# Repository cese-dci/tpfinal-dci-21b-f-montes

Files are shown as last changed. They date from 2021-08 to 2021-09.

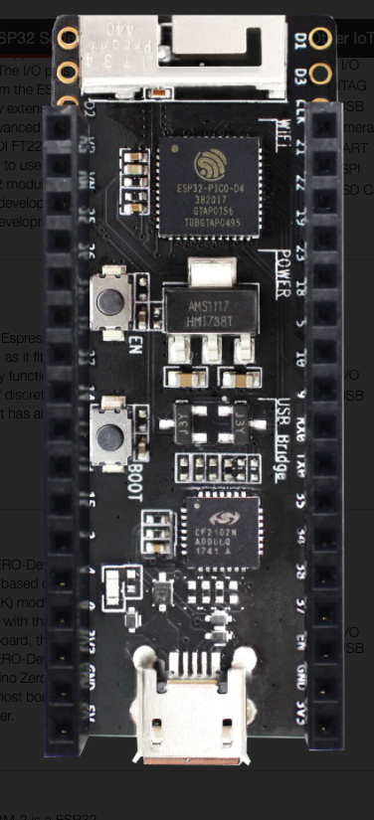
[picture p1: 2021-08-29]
info/ESP32-PICO-KIT_Vista_Superior_2.png

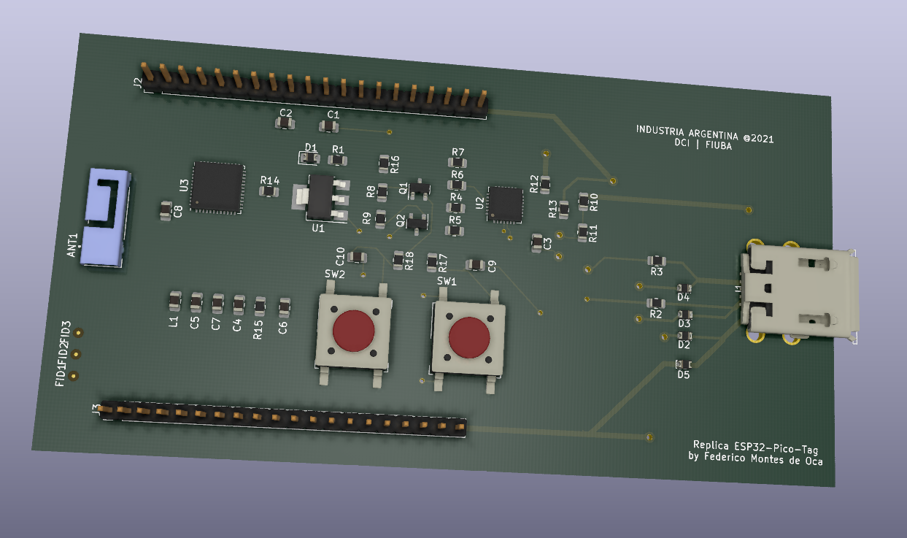
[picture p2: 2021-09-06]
pcb/MontesDeOca_DCI_CEIoT_Final_3D.png

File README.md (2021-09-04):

## Trabajo práctico final de la asignatura DCI ##
Este repositorio contiene el trabajo práctico final para la asignatura de Diseño de Circuitos Impresos de la carrera de posgrado de FIUBA.

* Autor: FEDERICO MONTES DE OCA
* Título corto del trabajo: REPLICA ESP32-PICO-KIT
* Descripción:  Circuito Impreso Replica de Modulo ESP32-PICO-KIT

## Licencia de este trabajo ##
Licencia OHL. Para detalles ver https://ohwr.org/cernohl

## Estructura del Repo ##

El repo cuenta con tres directorios principales donde encontraremos lo siguiente:

* doc: Toda la información sobre el circuito, principalmente propia:
  * Documnetacion de trabajo del autor
* info: Toda la iformación recolectada, principalmente de terceros:
  * Esquematicos provistos por el fabricante
  * BOM provista por el fabricante
  * PCB provistos por el fabricante
  * Info en internet
* pcb: Archivos de diseño esquemático y pcb propios.

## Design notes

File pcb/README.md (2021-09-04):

## Archivos Kicad ##

En este directorio se incluyen:

* Archivos de proyecto.
* Esquemático.
* PCB.
* Modelos  3D.
* Bibliotecas de símbolos y huellas externas.

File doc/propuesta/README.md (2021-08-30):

## Propuesta ##

Se adjunta aqui el material originalmente considerado para realizar el trabajo. Se incluye hipervinculo a la web del fabricante con todo el detalle: https://docs.espressif.com/projects/esp-idf/en/latest/esp32/hw-reference/esp32/get-started-pico-kit.html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

Tambien se adjuntan fotografias y esquematico tomado como referencias.

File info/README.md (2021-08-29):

## Información complementaria ##
Se adjuntan los pdf disponibilizados por el fabricante (ESPRESSIF) que poseen un importante nivel de detalle.

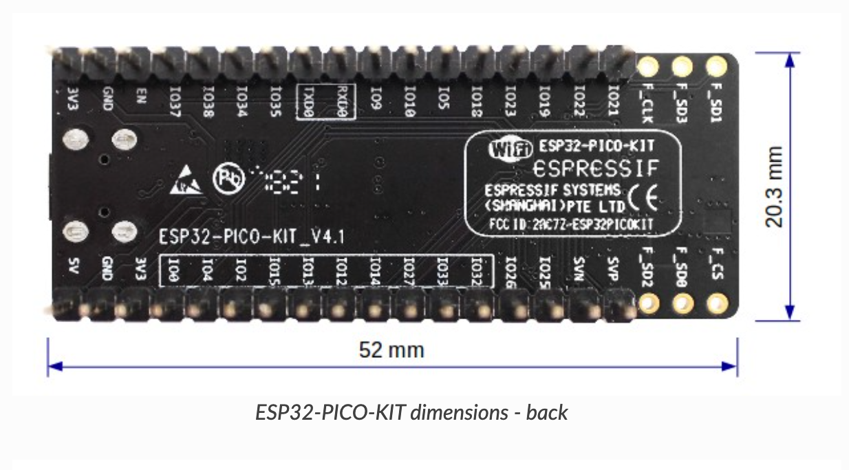
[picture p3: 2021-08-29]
info/ESP32-PICO-KIT_Vista_Inferior.png

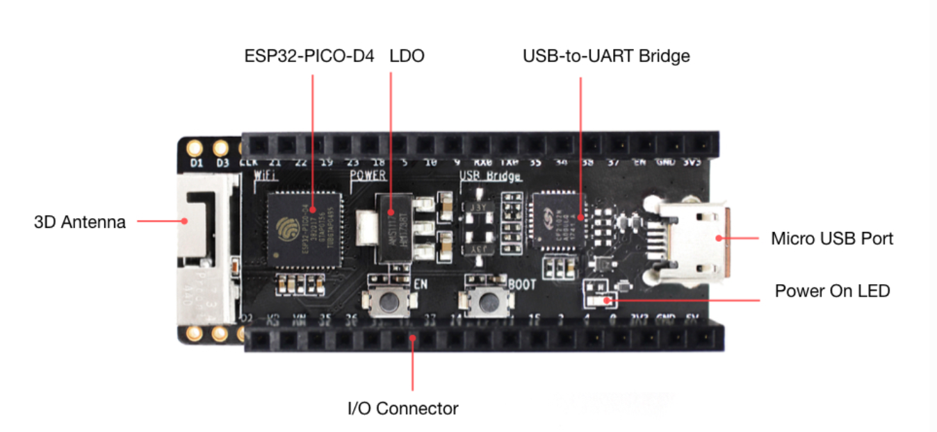
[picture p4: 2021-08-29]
info/ESP32-PICO-KIT_Vista_Superior.png

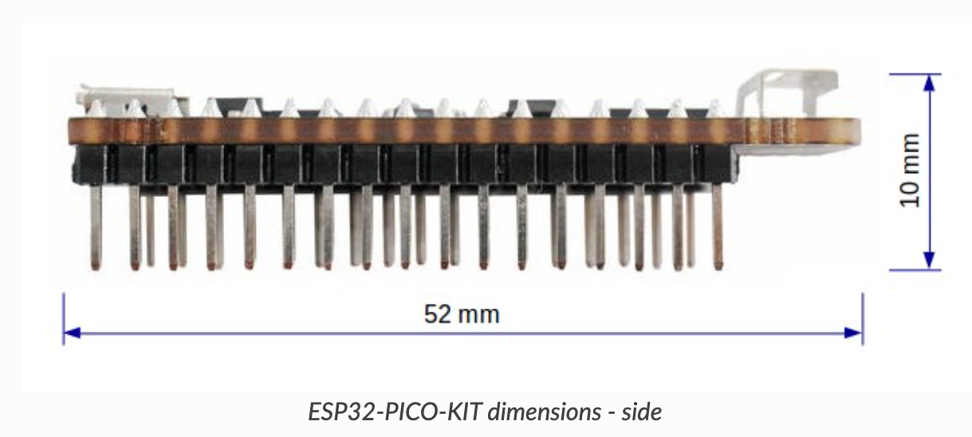
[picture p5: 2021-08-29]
info/ESP32-PICO-KIT_Vista_Lateral.png

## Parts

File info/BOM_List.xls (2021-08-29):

ESP32-PICO-KIT_V4.1 BOM_List(V0.9)
ID | Qty | Ref Des | Value | Package | ICs | Description
1 | 1 | ANT1 | Proant440 | PROANTONBOARD440 | Antenna | 3D Antenna
2 | 2 | C2,C4 | 10uF/25V(10%) | 0603C | Capacitance | Ceramic Capacitor
3 | 5 | C6,C7,C12,C16,C19 | 0.1uF/25V(10%) | 0402C | Capacitance | Ceramic Capacitor
4 | 1 | C15 | 10uF/6.3V(10%) | 0402C | Capacitance | Ceramic Capacitor
5 | 1 | C17 | 2.7pF±0.5pF/25V | 0402C | Capacitor | Ceramic Capacitor
6 | 1 | C18 | 1.6nH±0.3nH | 0402C | Inductor | Inductor
7 | 1 | D1 | RED LED | 0603D/A | LED | Red LED
8 | 1 | D2 | BAT760-7 | SOD-323 | Diode | Diode
9 | 3 | D3,D4,D5 | LESD5D5.0CT1G | SOD-523 | ESD | ESD 5V
10 | 1 | J1 | USB_CON8 | USB_5P | Connector | USB Connector
11 | 2 | J2,J3 | 2.54mm single-row pin headers 17P | CON20_2P54 | Connector | Male Header
12 | 1 | L1 | 4.7pF±0.5pF/25V | 0402C | Capacitor | Ceramic Capacitor
13 | 2 | Q1,Q2 | S8050(NPN) | SOT-23-3 | Transistor | Transistor(NPN)
14 | 2 | R1,R27 | 2K(1%) | 0402R | Resistor | Resistor
15 | 5 | R3,R4,R6,R7,R21 | 0R(1%) | 0402R | Resistor | Resistor
16 | 2 | R15,R16 | 1K(1%) | 0402R | Resistor | Resistor
17 | 3 | R19,R20,R22 | 10K(1%) | 0402R | Resistor | Resistor
18 | 1 | R24 | 22.1K(1%) | 0402R | Resistor | Resistor
19 | 1 | R26 | 47.5K(1%) | 0402R | Resistor | Resistor
20 | 2 | SW1,SW2 | SW PUSHBUTTON | SW_3X4X2MM | Push Button | Push Button
21 | 1 | U1 | AMS1117-3.3 | SOT-223 | Power IC | Power IC
22 | 1 | U4 | CP2102N | QFN28-5X5-0P5 | IC Chip | USB2UART Bridge
23 | 1 | U5 | ESP32-PICO-D4 | QFN48_7X7 | IC Chip | ESP32-SIP

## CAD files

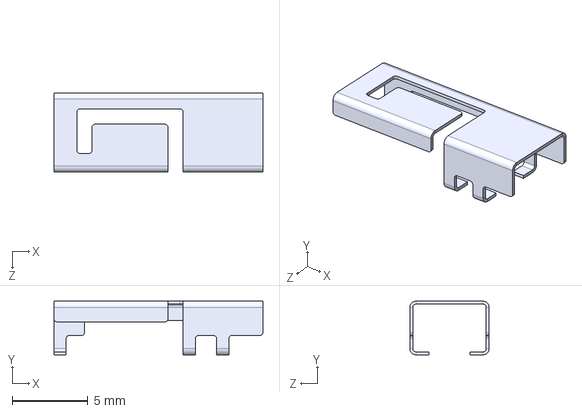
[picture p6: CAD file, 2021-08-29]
pcb/PRO-OB-440.step
13.8 x 3.53 x 5.23 mm

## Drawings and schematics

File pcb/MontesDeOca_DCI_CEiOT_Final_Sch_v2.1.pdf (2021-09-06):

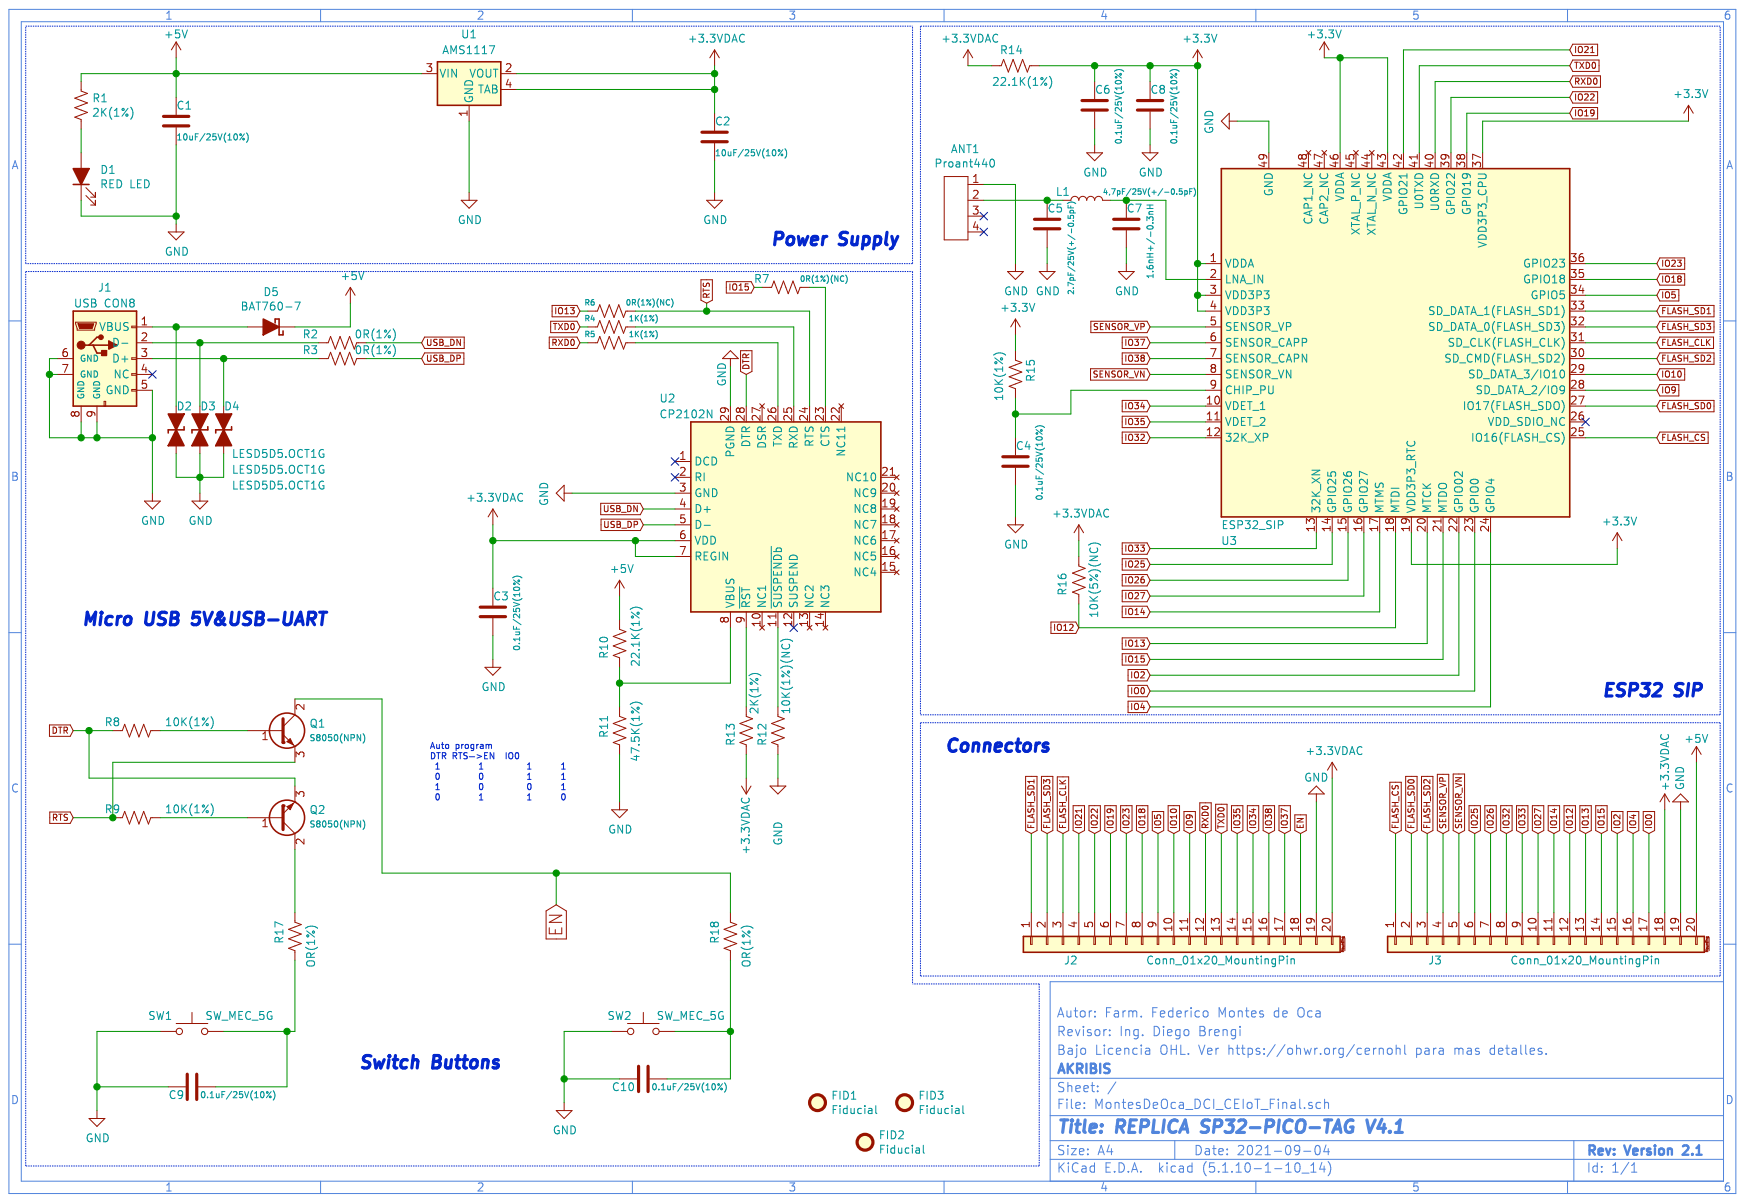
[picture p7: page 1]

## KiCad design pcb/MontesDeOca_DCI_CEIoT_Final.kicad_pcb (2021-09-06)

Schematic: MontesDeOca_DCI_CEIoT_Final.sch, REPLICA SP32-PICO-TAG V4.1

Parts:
ANT1: Proant440; ANT_PRO-OB-440
C1, C2: 10uF/25V(10%); C_0805_2012Metric
C3, C4, C6, C8, C9, C10: 0.1uF/25V(10%); C_0805_2012Metric
C5: 2.7pF/25V(+/-0.5pF); C_0805_2012Metric
C7: 1.6nH+/-0.3nH; C_0805_2012Metric
D1: RED LED; LED_0805_2012Metric
D2, D3, D4: LESD5D5.OCT1G; D_SOD-523
D5: BAT760-7; D_SOD-523
FID1, FID2, FID3: Fiducial; Fiducial_0.5mm_Mask1.5mm
J1: USB CON8; USB_A_Wuerth_61400826021_Horizontal_Stacked; Manufacturer Part # DX4R005JJ2R1800
J2, J3: Conn_01x20_MountingPin; PinHeader_1x20_P2.54mm_Vertical
L1: 4,7pF/25V(+/-0.5pF); C_0805_2012Metric
Q1, Q2: S8050(NPN); SOT-23
R1, R13: 2K(1%); R_0805_2012Metric
R2, R3: 0R(1%); R_0805_2012Metric
R4, R5: 1K(1%); R_0805_2012Metric
R6, R7: 0R(1%)(NC); R_0805_2012Metric
R8, R9, R15: 10K(1%); R_0805_2012Metric
R10, R14: 22.1K(1%); R_0805_2012Metric
R11: 47.5K(1%); R_0805_2012Metric
R12: 10K(1%)(NC); R_0805_2012Metric
R16: 10K(5%)(NC); R_0805_2012Metric
R17, R18: OR(1%); R_0805_2012Metric
SW1, SW2: SW_MEC_5G; SW_MEC_5GSH9
U1: AMS1117; SOT-223
U2: CP2102N; QFN-28-1EP_5x5mm_P0.5mm_EP3.35x3.35mm
U3: ESP32_SIP; QFN-48-1EP_7x7mm_P0.5mm_EP5.3x5.3mm

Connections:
+3.3VDAC: C2.1, C3.1, J2.20, J3.18, R13.2, R14.2, R16.2, U1.2 (VOUT), U1.4 (TAB), U2.6 (VDD), U2.7 (REGIN)
+3V3: C6.1, C8.1, R14.1, R15.2, U3.1 (VDDA), U3.3 (VDD3P3), U3.4 (VDD3P3), U3.19 (VDD3P3_RTC), U3.37 (VDD3P3_CPU), U3.43 (VDDA), U3.46 (VDDA)
+5V: C1.1, D5.1 (K), J3.20, R1.1, R10.1, U1.3 (VIN)
DTR: Q2.3 (E), R8.1, U2.28 (DTR)
EN: J2.18, Q1.2 (C), R18.1
FLASH_CLK: J2.3, U3.31 (SD_CLK(FLASH_CLK))
FLASH_CS: J3.1, U3.25 (IO16(FLASH_CS))
FLASH_SD0: J3.2, U3.27 (IO17(FLASH_SDO))
FLASH_SD1: J2.1, U3.33 (SD_DATA_1(FLASH_SD1))
FLASH_SD2: J3.3, U3.30 (SD_CMD(FLASH_SD2))
FLASH_SD3: J2.2, U3.32 (SD_DATA_0(FLASH_SD3))
GND: ANT1.1, C1.2, C2.2, C3.2, C4.2, C5.2, C6.2, C7.2, C8.2, C9.2, C10.2, D1.1 (K), D2.2 (A2), D3.2 (A2), D4.2 (A2), J1.5 (GND), J1.6 (GND), J1.7 (GND), J1.8 (GND), J1.9 (GND), J2.19, J3.19, R11.2, R12.2, SW1.1 (A), SW1.2 (A), SW2.1 (A), SW2.2 (A), U1.1 (GND), U2.3 (GND), U2.29 (PGND), U3.49 (GND)
IO0: J3.17, U3.23 (GPIO0)
IO2: J3.15, U3.22 (GPIO02)
IO4: J3.16, U3.24 (GPIO4)
IO5: J2.9, U3.34 (GPIO5)
IO9: J2.11, U3.28 (SD_DATA_2/IO9)
IO10: J2.10, U3.29 (SD_DATA_3/IO10)
IO12: J3.12, R16.1, U3.18 (MTDI)
IO13: J3.13, R6.1, U3.20 (MTCK)
IO14: J3.11, U3.17 (MTMS)
IO15: J3.14, R7.1, U3.21 (MTDO)
IO18: J2.8, U3.35 (GPIO18)
IO19: J2.6, U3.38 (GPIO19)
IO21: J2.4, U3.42 (GPIO21)
IO22: J2.5, U3.39 (GPIO22)
IO23: J2.7, U3.36 (GPIO23)
IO25: J3.6, U3.14 (GPIO25)
IO26: J3.7, U3.15 (GPIO26)
IO27: J3.10, U3.16 (GPIO27)
IO32: J3.8, U3.12 (32K_XP)
IO33: J3.9, U3.13 (32K_XN)
IO34: J2.15, U3.10 (VDET_1)
IO35: J2.14, U3.11 (VDET_2)
IO37: J2.17, U3.6 (SENSOR_CAPP)
IO38: J2.16, U3.7 (SENSOR_CAPN)
unnamed: ANT1.2, C5.1, L1.1
unnamed: C4.1, R15.1, U3.9 (CHIP_PU)
unnamed: C7.1, L1.2, U3.2 (LNA_IN)
unnamed: C9.1, R17.2, SW1.3 (B), SW1.4 (B)
unnamed: C10.1, R18.2, SW2.3 (B), SW2.4 (B)
unnamed: D1.2 (A), R1.2
unnamed: D2.1 (A1), D5.2 (A), J1.1 (VBUS)
unnamed: D3.1 (A1), J1.2 (D-), R2.1
unnamed: D4.1 (A1), J1.3 (D+), R3.1
unnamed: Q1.1 (B), R8.2
unnamed: Q2.1 (B), R9.2
unnamed: Q2.2 (C), R17.1
unnamed: R4.2, U2.25 (RXD)
unnamed: R5.2, U2.26 (TXD)
unnamed: R7.2, U2.23 (CTS)
unnamed: R10.2, R11.1, U2.8 (VBUS)
unnamed: R12.1, U2.11 (~SUSPENDb)
unnamed: R13.1, U2.9 (~RST)
RTS: Q1.3 (E), R6.2, R9.1, U2.24 (RTS)
RXD0: J2.12, R5.1, U3.40 (U0RXD)
SENSOR_VN: J3.5, U3.8 (SENSOR_VN)
SENSOR_VP: J3.4, U3.5 (SENSOR_VP)
TXD0: J2.13, R4.1, U3.41 (U0TXD)
USB_DN: R2.2, U2.4 (D+)
USB_DP: R3.2, U2.5 (D-)

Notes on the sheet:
Auto program DTR RTS—>EN IO0 1 1 1 1 0 0 1 1 1 0 0 1 0 1 1 0
Power Supply
ESP32 SIP
Micro USB 5V&USB-UART
Switch Buttons
Connectors

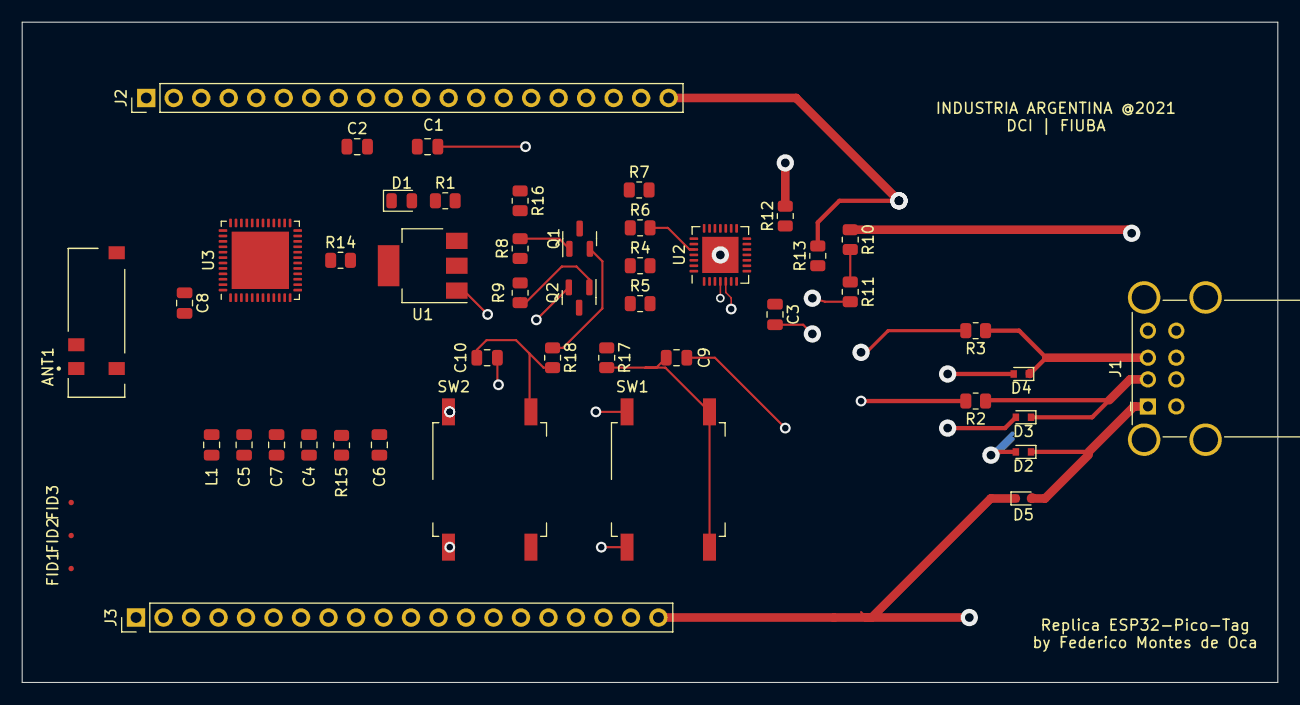
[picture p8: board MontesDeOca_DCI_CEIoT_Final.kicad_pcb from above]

Board: 4 copper layers, 116.0 x 61.0 mm, 48 parts (0 on the bottom side), 61 nets.

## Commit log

2021-09-04 Update README.md
    Actualizacion de los terminos de licenciamiento
2021-09-06 Actualizacion segun correcciones ralizadas
    Se avanzo adicionalmente en el posicionamiento de los componentes, el ruteo y el modelo 3D
    [MontesDeOca_DCI_CEIoT_Final.kicad_pcb, MontesDeOca_DCI_CEIoT_Final.sch]
